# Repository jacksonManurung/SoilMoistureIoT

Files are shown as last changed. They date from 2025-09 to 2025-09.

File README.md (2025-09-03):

# Soil Moisture IoT
Eclosure+SoilMoistureIoT_page-0001
WhatsApp Image 2025-09-03 at 09 00 22_e6ffbfff

## Skematik
SoilMoistureIoT_page-0001

## Koneksi microcontroller dan komponen pasif pendukung
SoilMoistureIoT_page-0002

## Modem dengan beberapa disain komponen pasif pendukung
SoilMoistureIoT_page-0003

## Disain "capacitor decoupling" untuk modem
SoilMoistureIoT_page-0004

## Disain konektor "SIM Card" untuk modem
SoilMoistureIoT_page-0005

## Disain indikator untuk modem
SoilMoistureIoT_page-0006

## Media penyimpanan menggunakan F-RAM
SoilMoistureIoT_page-0007

## Komponen aktif untuk backup system terpisah
SoilMoistureIoT_page-0008

## Antarmuka sensor
SoilMoistureIoT_page-0009

## Disain "multi-purpose" DC regulator dan battery power management system
SoilMoistureIoT_page-0010

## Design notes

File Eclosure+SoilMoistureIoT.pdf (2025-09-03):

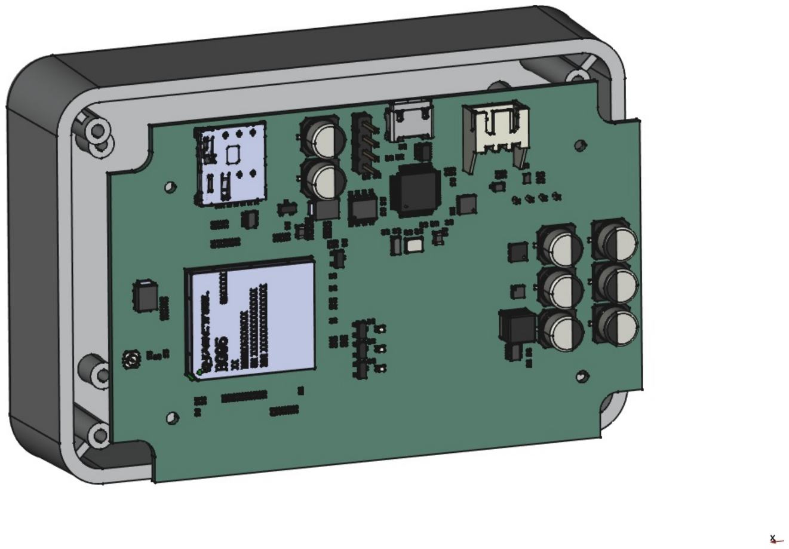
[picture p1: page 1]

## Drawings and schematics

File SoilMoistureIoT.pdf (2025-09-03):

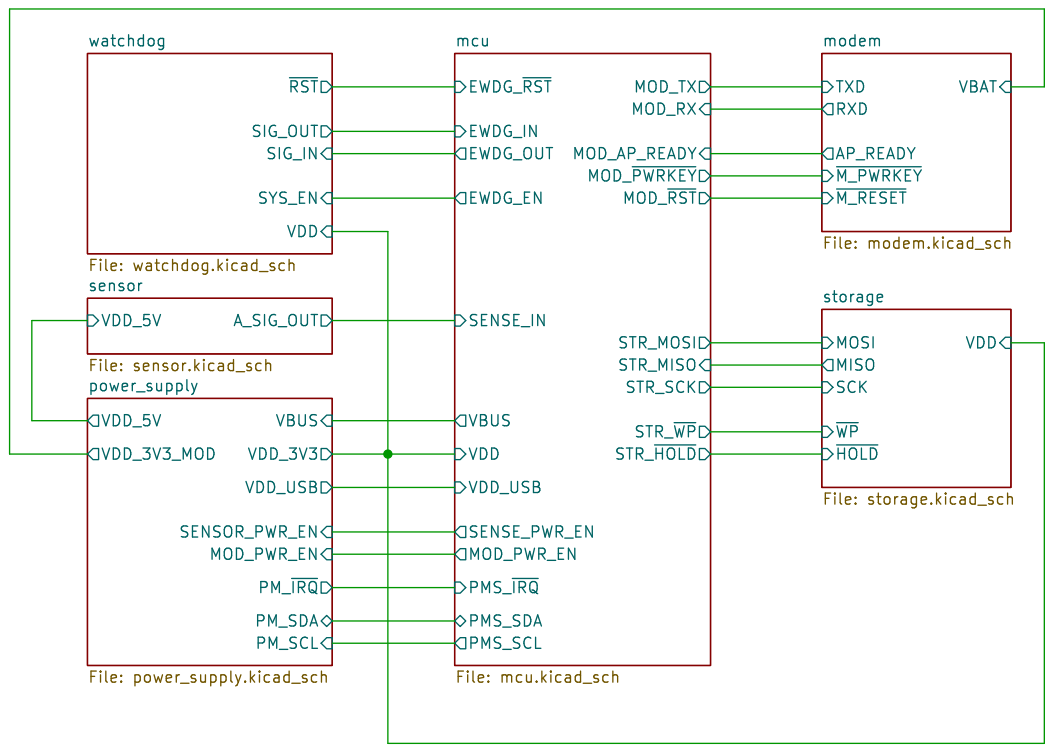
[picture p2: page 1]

Id: 1/10 Title: File: SoilMoistureIoT.kicad_sch Sheet: / STR_~{HOLD} MOD_TX MOD_RX

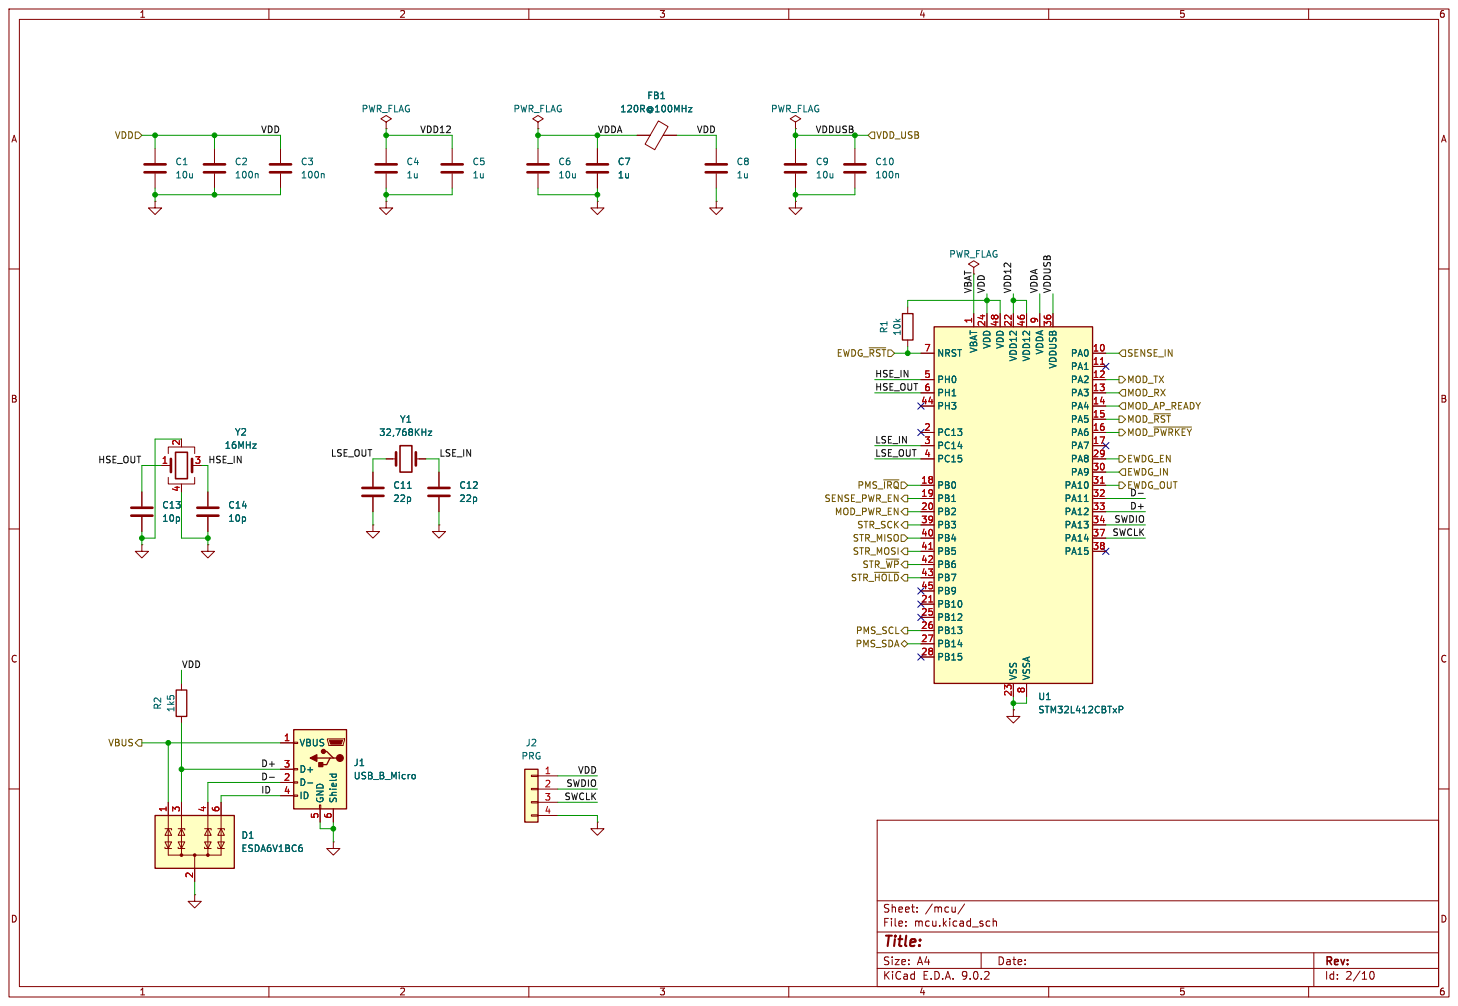
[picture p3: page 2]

Id: 2/10 Title: File: mcu.kicad_sch Sheet: /mcu/ R1 10k

1 VDD 24 VDD 48 VDD12 22 VSS 23 VDD12 46 VSSA

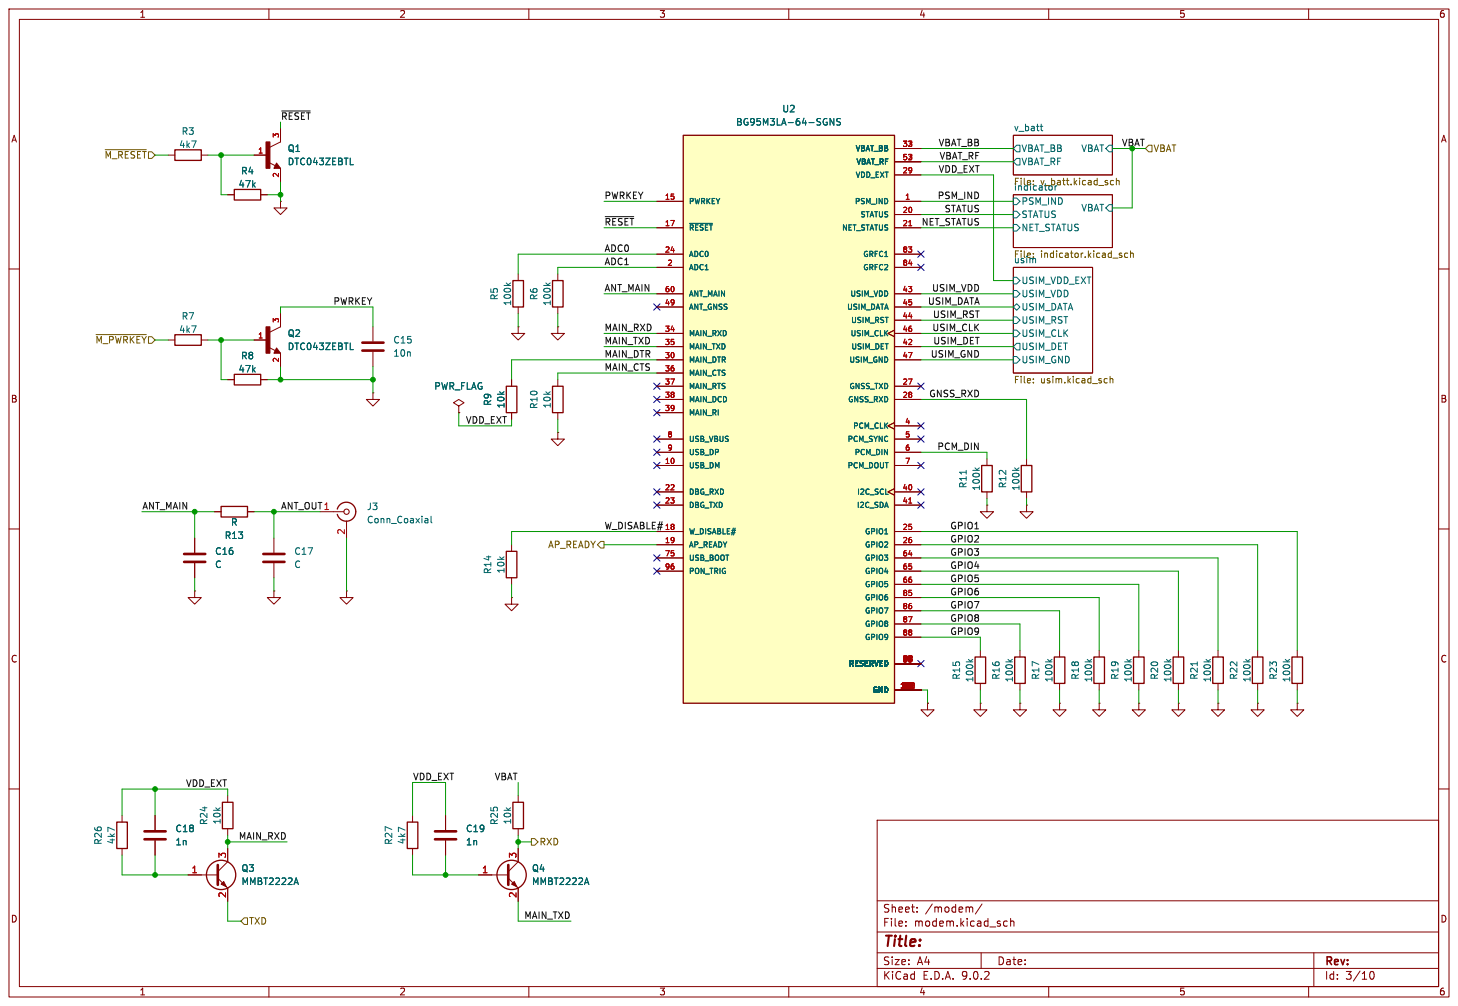
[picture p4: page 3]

Id: 3/10 Title: File: modem.kicad_sch Sheet: /modem/

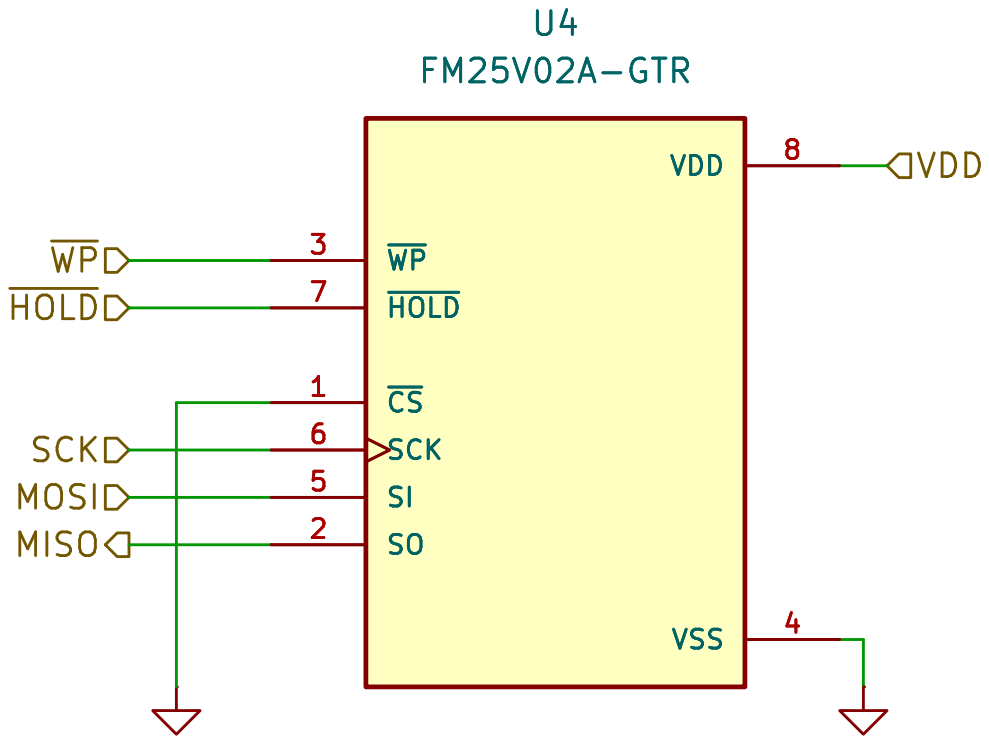
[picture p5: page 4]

Id: 7/10 Title: File: storage.kicad_sch Sheet: /storage/

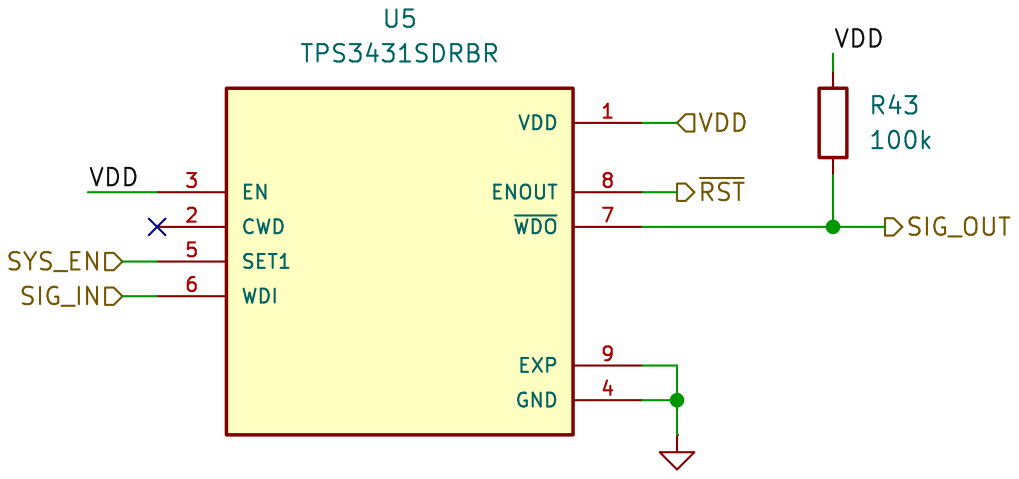
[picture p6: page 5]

Id: 8/10 Title: File: watchdog.kicad_sch Sheet: /watchdog/

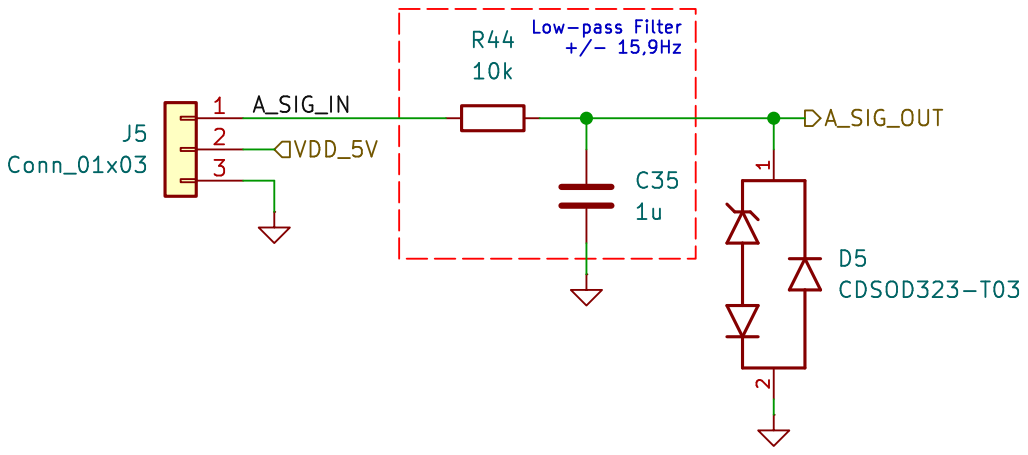
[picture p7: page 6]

Id: 9/10 Title: File: sensor.kicad_sch Sheet: /sensor/

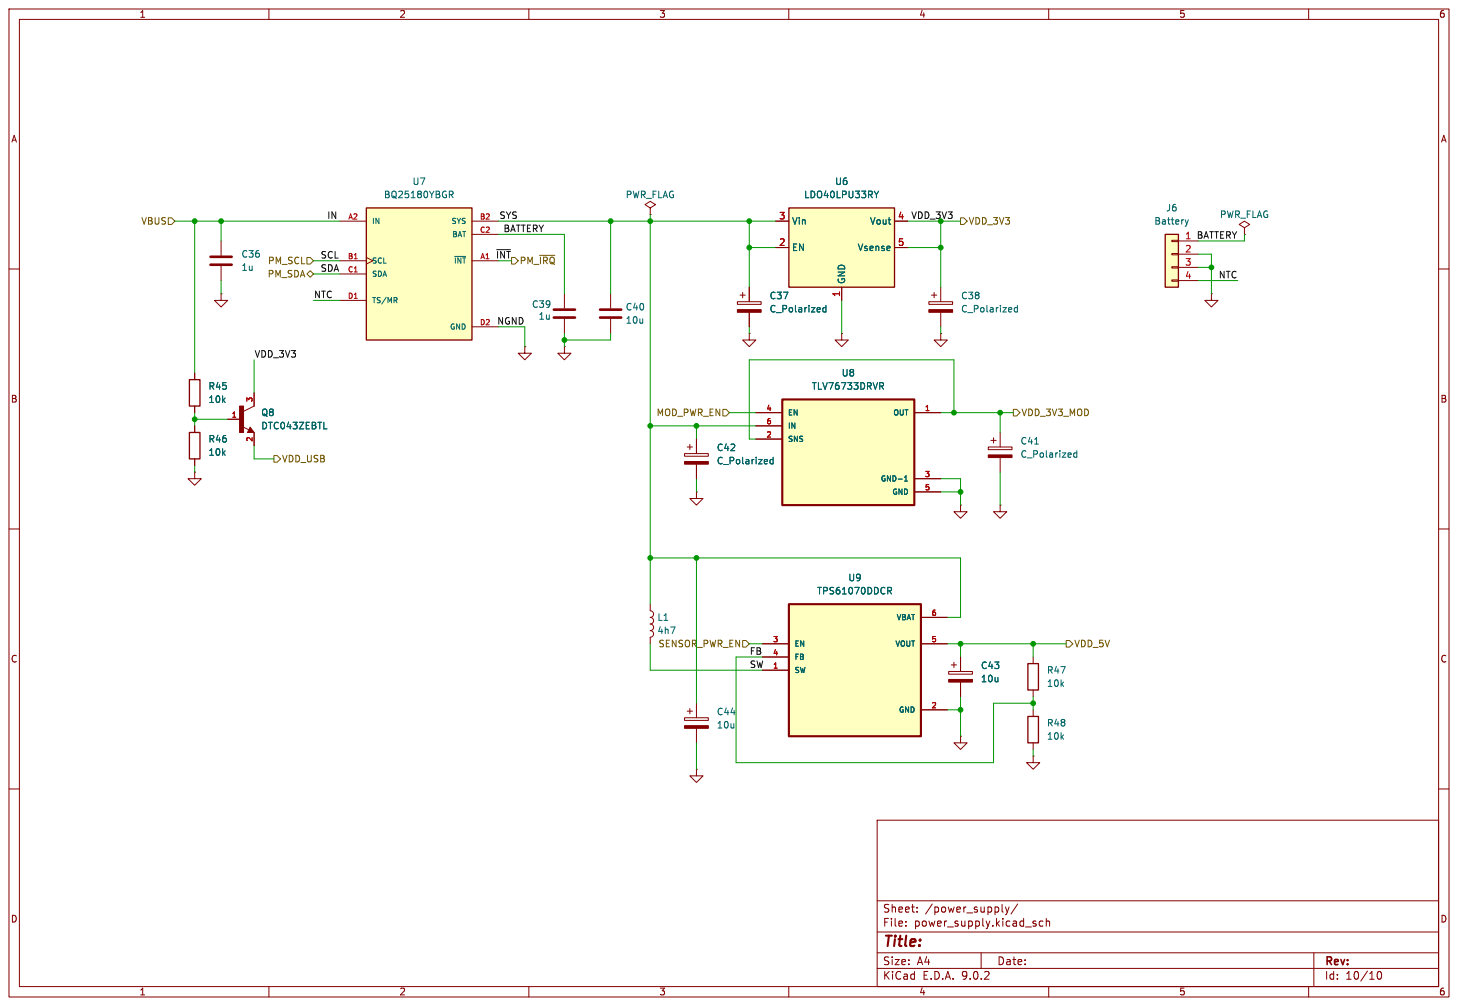
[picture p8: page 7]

Id: 10/10 Title: File: power_supply.kicad_sch Sheet: /power_supply/

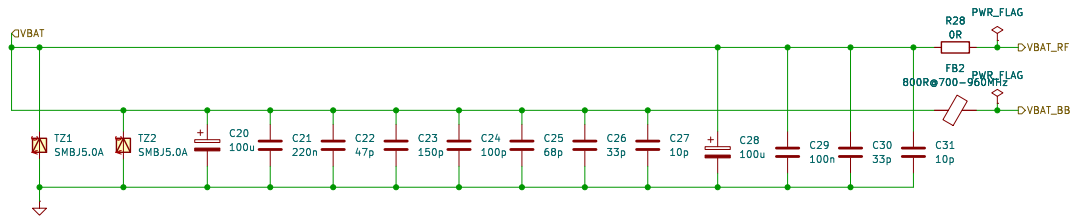
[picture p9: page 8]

Id: 4/10 Title: File: v_batt.kicad_sch Sheet: /modem/v_batt/ C21

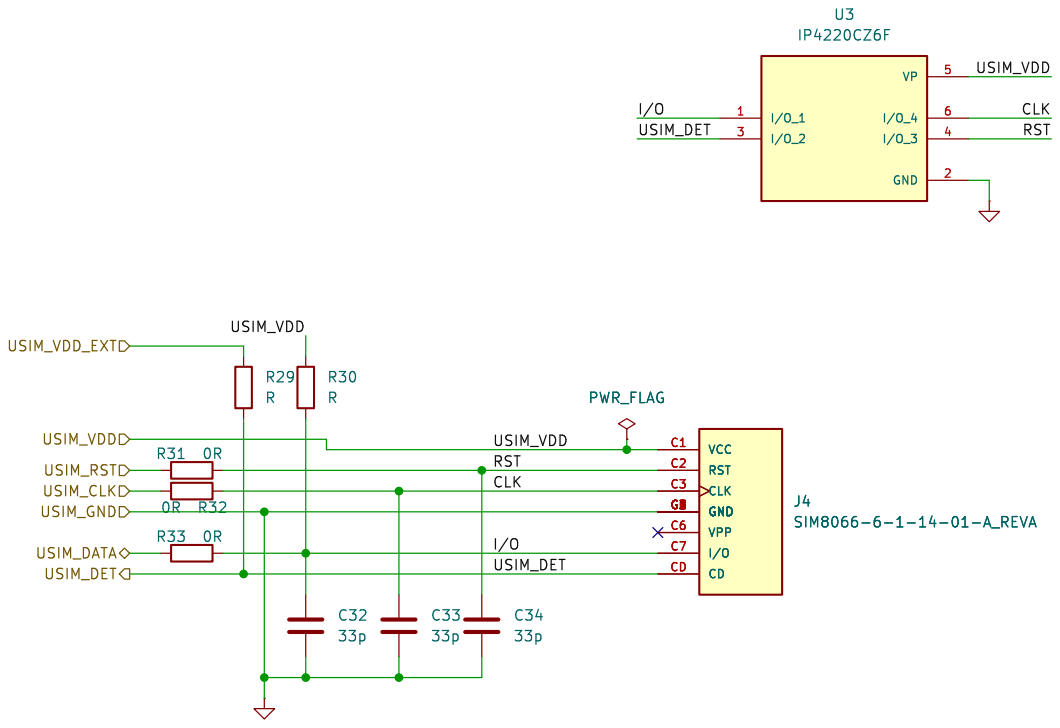
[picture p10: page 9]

Id: 5/10 Title: File: usim.kicad_sch Sheet: /modem/usim/ R31 0R

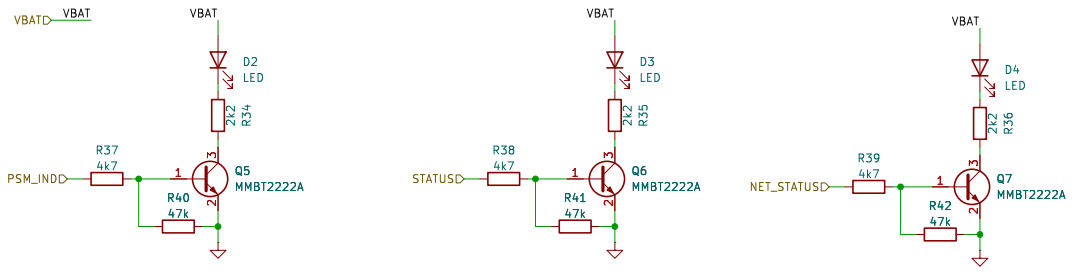
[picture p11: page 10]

Id: 6/10 Title: File: indicator.kicad_sch Sheet: /modem/indicator/

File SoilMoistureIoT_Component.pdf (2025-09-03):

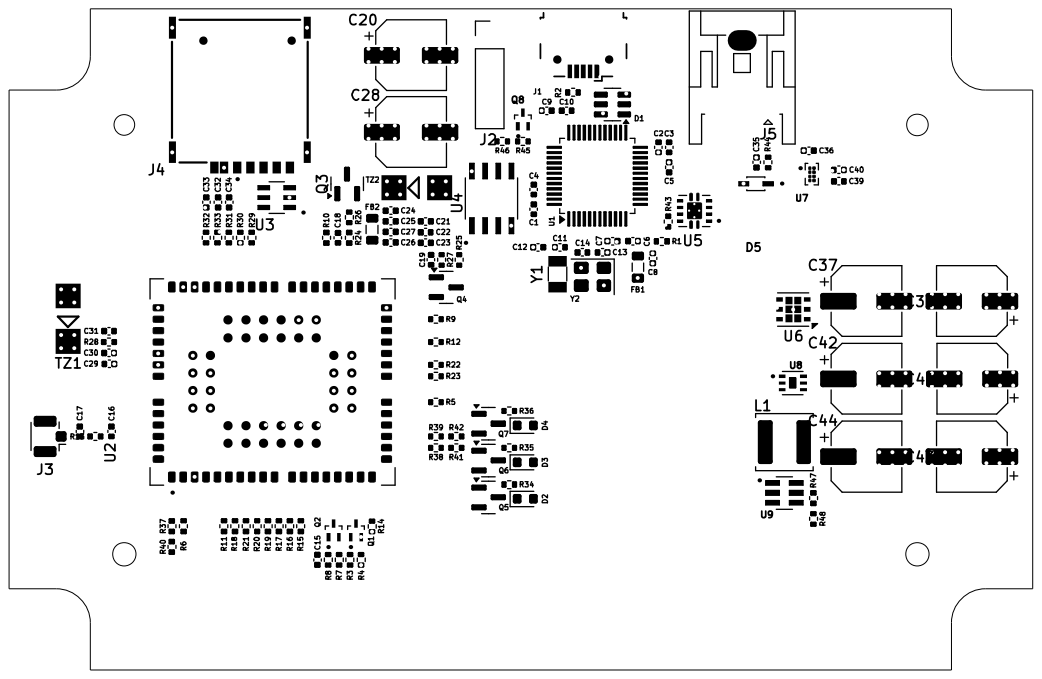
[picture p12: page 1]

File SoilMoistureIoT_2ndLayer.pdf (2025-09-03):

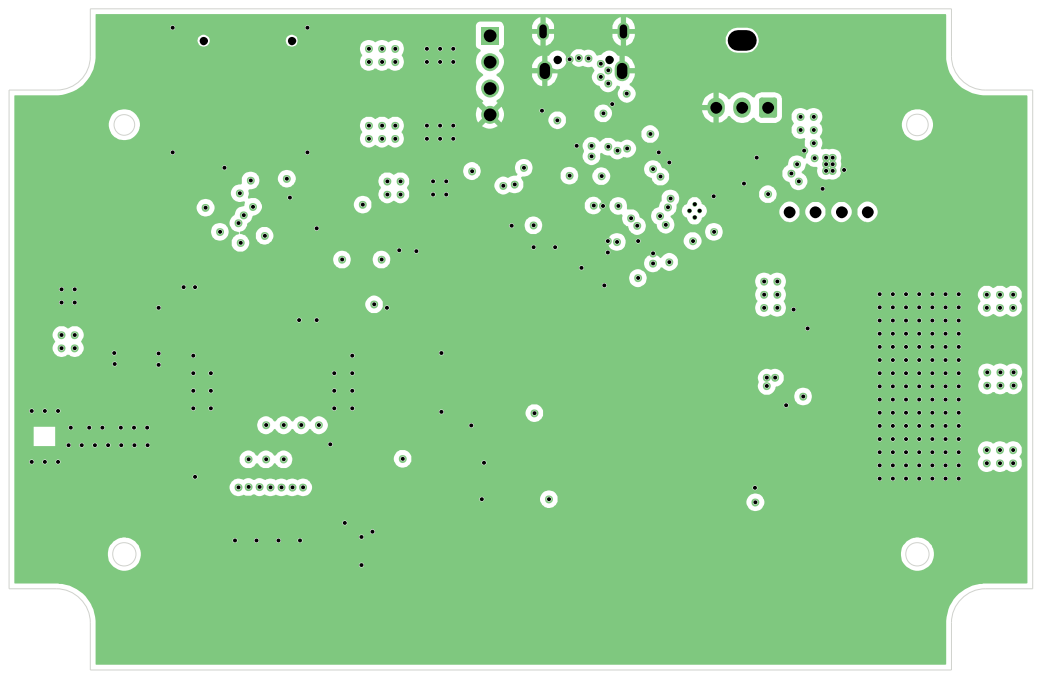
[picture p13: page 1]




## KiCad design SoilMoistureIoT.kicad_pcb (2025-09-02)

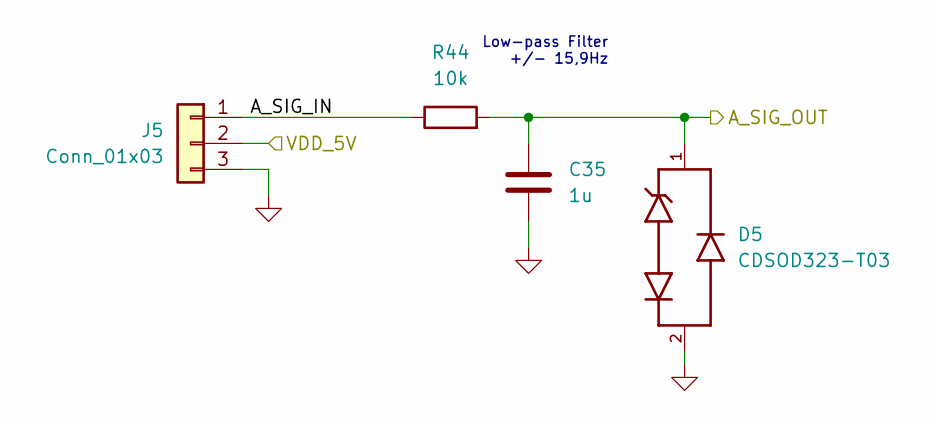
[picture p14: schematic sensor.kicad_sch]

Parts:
C35: 1u; C_0402_1005Metric
D5: CDSOD323-T03; SOD2513X114N; PARTREV 04/23
J5: Conn_01x03; JST_XA_S03B-XASK-1_1x03_P2.50mm_Horizontal
R44: 10k; R_0402_1005Metric

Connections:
/mcu/SENSE_IN: C35.1, D5.1, R44.2; also elsewhere on the board
/power_supply/VDD_5V: J5.2; also elsewhere on the board
/sensor/A_SIG_IN: J5.1, R44.1
GND: C35.2, D5.2, J5.3; also elsewhere on the board

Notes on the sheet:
Low-pass Filter +/- 15,9Hz

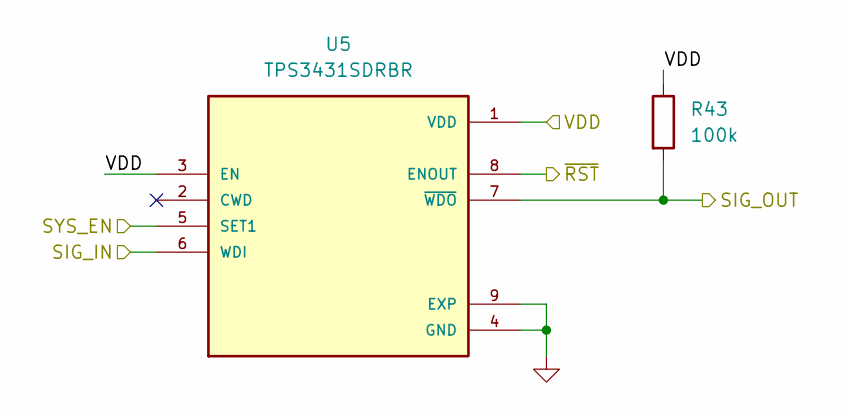
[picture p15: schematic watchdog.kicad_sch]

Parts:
R43: 100k; R_0402_1005Metric
U5: TPS3431SDRBR; IC_TPS3431SDRBR; PARTREV A

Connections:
/mcu/EWDG_EN: U5.5 (SET1); also elsewhere on the board
/mcu/EWDG_IN: R43.2, U5.7 (~WDO); also elsewhere on the board
/mcu/EWDG_OUT: U5.6 (WDI); also elsewhere on the board
/mcu/EWDG_~RST: U5.8 (ENOUT); also elsewhere on the board
/mcu/VDD: R43.1, U5.1 (VDD), U5.3 (EN); also elsewhere on the board
GND: U5.4 (GND), U5.9 (EXP); also elsewhere on the board

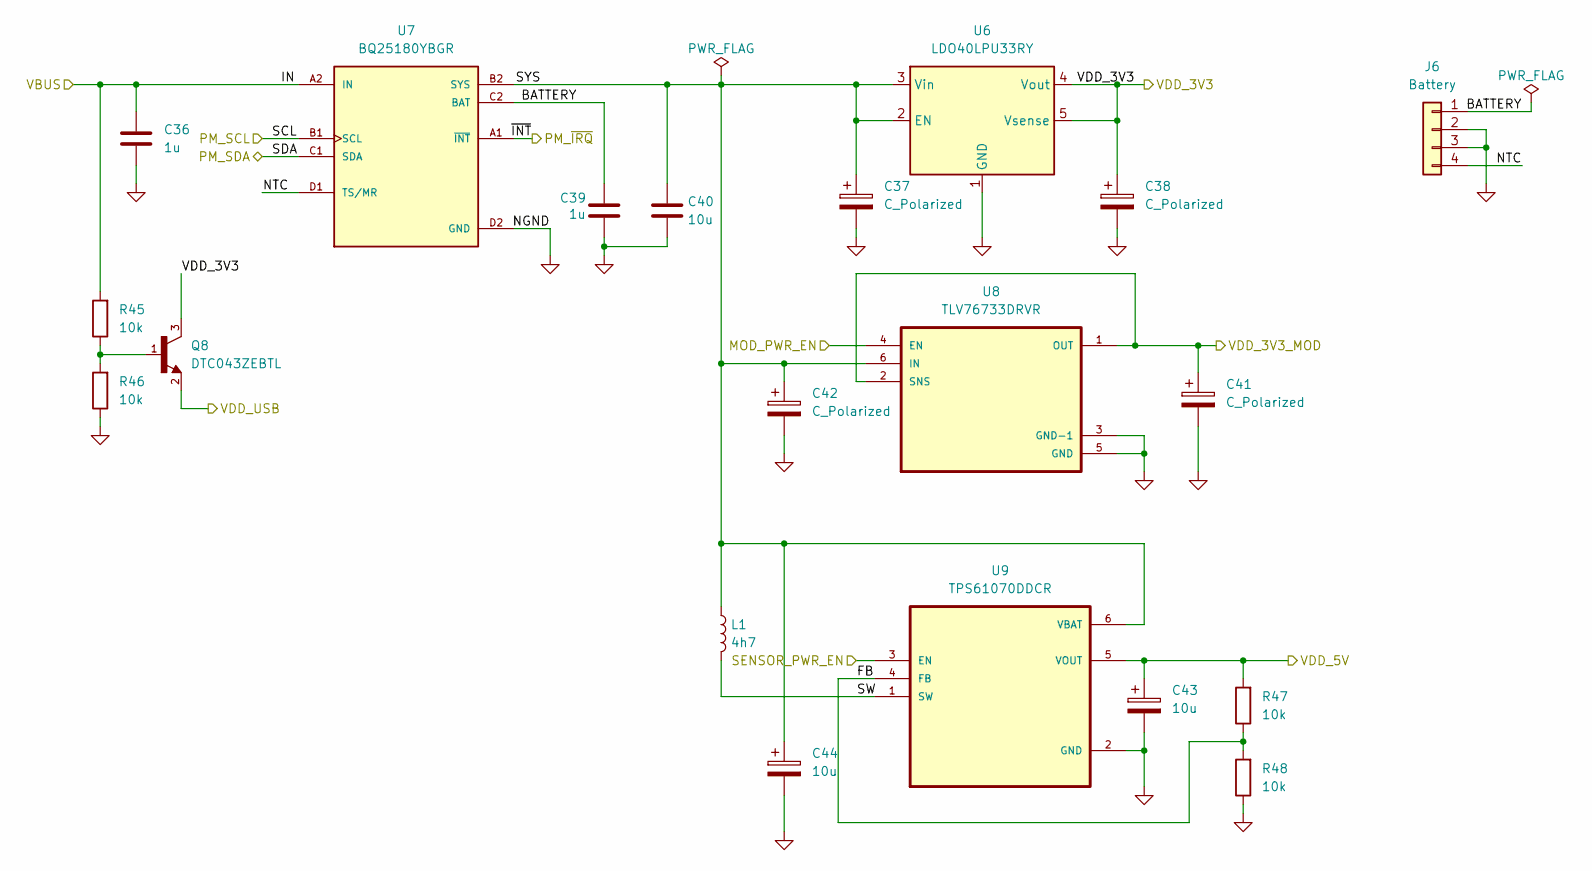
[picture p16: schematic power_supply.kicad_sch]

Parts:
C36, C39: 1u; C_0402_1005Metric
C37, C38, C41, C42: C_Polarized; CP_Elec_6.3x5.7
C40: 10u; C_0402_1005Metric
C43, C44: 10u; CP_Elec_6.3x5.7
J6: Battery; JST_XA_S04B-XASK-1N-BN_1x04_P2.50mm_Horizontal
L1: 4h7; L_APV_ANR5045
Q8: DTC043ZEBTL; SOTFL50P160X85-3N; PARTREV 002
R45, R46, R47, R48: 10k; R_0402_1005Metric
U6: LDO40LPU33RY; DFN-6-1EP_3x3mm_P0.95mm_EP1.7x2.6mm
U7: BQ25180YBGR; IC_BQ25180YBGR; PARTREV C
U8: TLV76733DRVR; SON65P200X200X80-7N
U9: TPS61070DDCR; SOT95P280X110-6N

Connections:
/mcu/MOD_PWR_EN: U8.4 (EN); also elsewhere on the board
/mcu/SENSE_PWR_EN: U9.3 (EN); also elsewhere on the board
/mcu/VDD: C38.1, Q8.3, U6.4 (Vout), U6.5 (Vsense); also elsewhere on the board
/mcu/VDDUSB: Q8.2; also elsewhere on the board
/modem/VBAT: C41.1, U8.1 (OUT), U8.2 (SNS); also elsewhere on the board
/power_supply/BATTERY: C39.1, J6.1, U7.C2 (BAT)
/power_supply/FB: R47.1, R48.2, U9.4 (FB)
/power_supply/IN: C36.1, R45.2, U7.A2 (IN); also elsewhere on the board
/power_supply/NTC: J6.4, U7.D1 (TS/MR)
/power_supply/SCL: U7.B1 (SCL); also elsewhere on the board
/power_supply/SDA: U7.C1 (SDA); also elsewhere on the board
/power_supply/SW: L1.2, U9.1 (SW)
/power_supply/SYS: C37.1, C40.1, C42.1, C44.1, L1.1, U6.2 (EN), U6.3 (Vin), U7.B2 (SYS), U8.6 (IN), U9.6 (VBAT)
/power_supply/VDD_5V: C43.1, R47.2, U9.5 (VOUT); also elsewhere on the board
/power_supply/~INT: U7.A1 (~INT); also elsewhere on the board
GND: C36.2, C37.2, C38.2, C39.2, C40.2, C41.2, C42.2, C43.2, C44.2, J6.2, J6.3, R46.1, R48.1, U6.1 (GND), U6.7 (GND), U7.D2 (GND), U8.3 (GND-1), U8.5 (GND), U9.2 (GND); also elsewhere on the board
unnamed: Q8.1, R45.1, R46.2

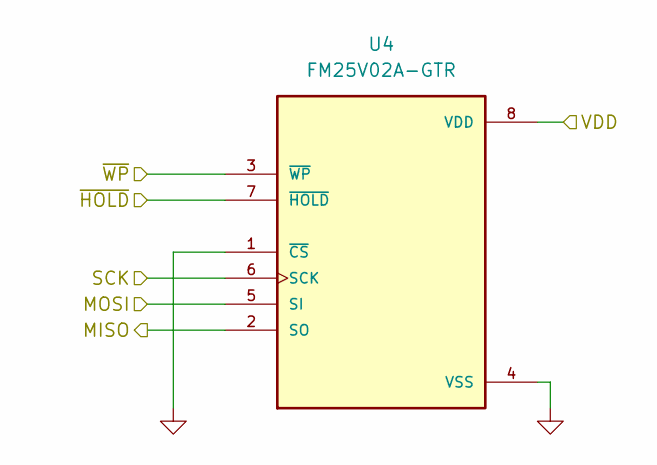
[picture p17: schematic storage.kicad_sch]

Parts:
U4: FM25V02A-GTR; SOIC127P602X172-8N

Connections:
/mcu/STR_MISO: U4.2 (SO); also elsewhere on the board
/mcu/STR_MOSI: U4.5 (SI); also elsewhere on the board
/mcu/STR_SCK: U4.6 (SCK); also elsewhere on the board
/mcu/STR_~HOLD: U4.7 (~HOLD); also elsewhere on the board
/mcu/STR_~WP: U4.3 (~WP); also elsewhere on the board
/mcu/VDD: U4.8 (VDD); also elsewhere on the board
GND: U4.1 (~CS), U4.4 (VSS); also elsewhere on the board

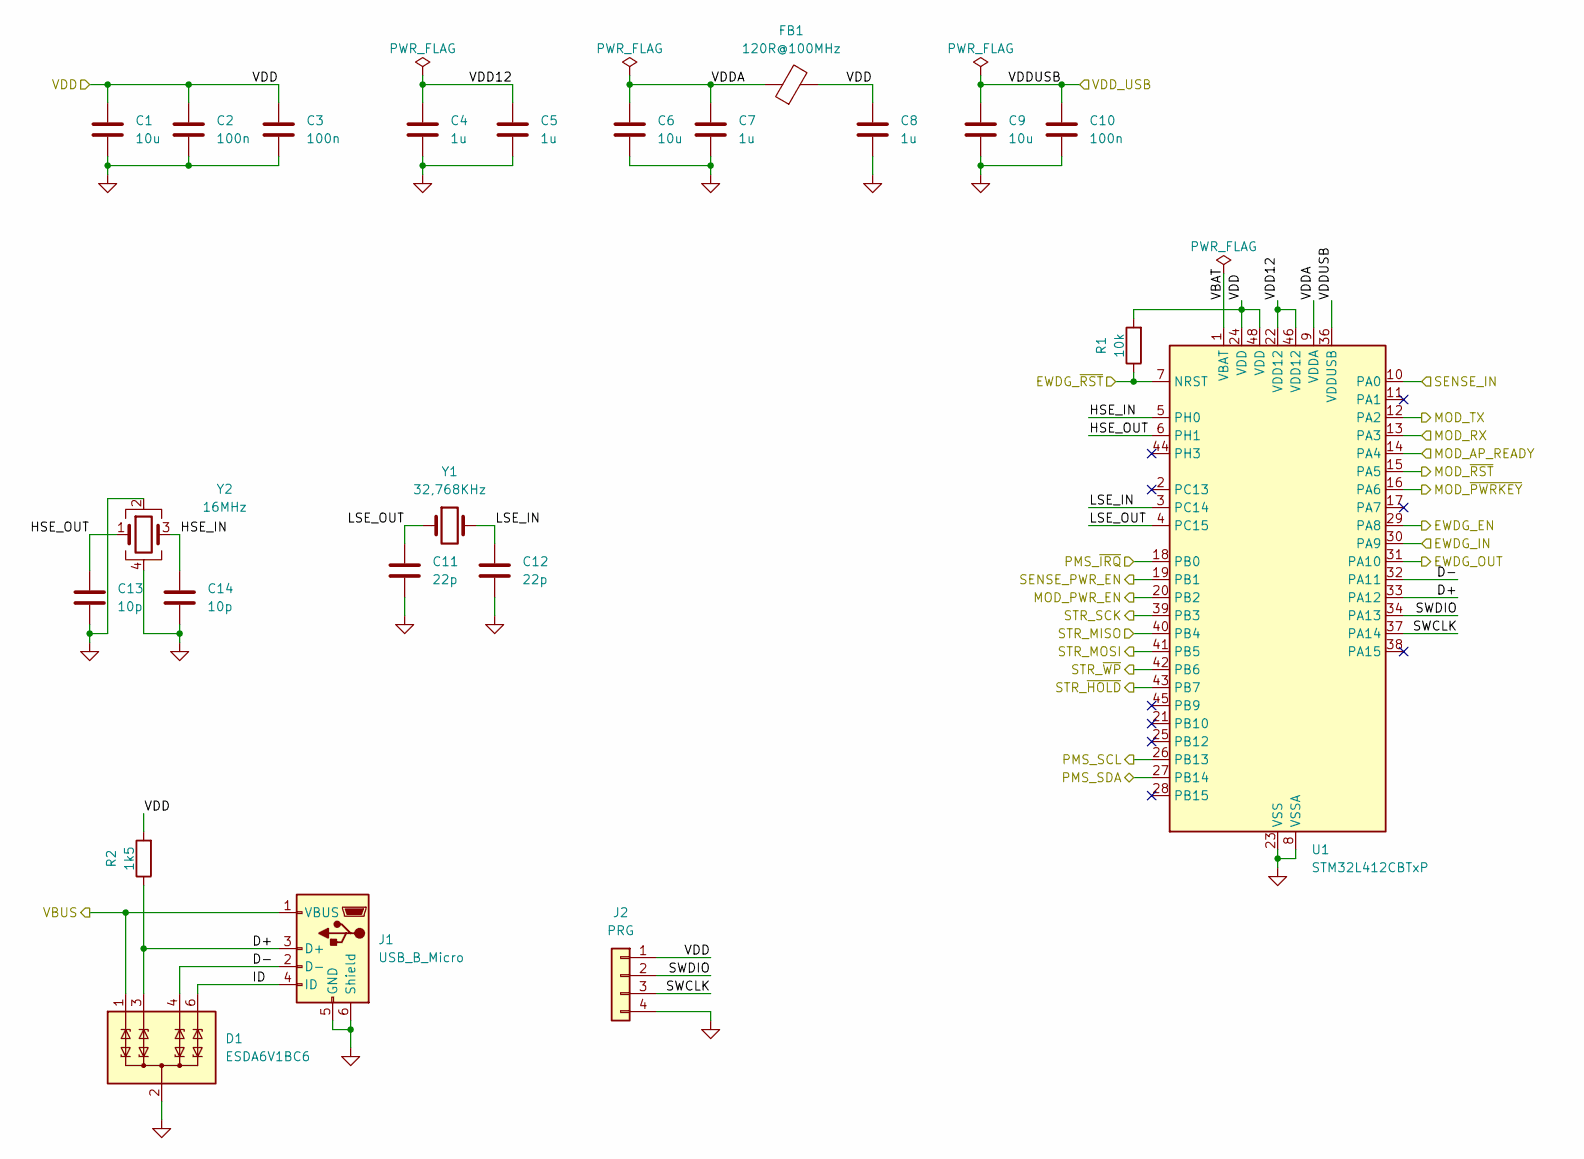
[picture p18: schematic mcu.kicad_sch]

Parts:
C1, C6, C9: 10u; C_0402_1005Metric
C2, C3, C10: 100n; C_0402_1005Metric
C4, C5, C7, C8: 1u; C_0402_1005Metric
C11, C12: 22p; C_0402_1005Metric
C13, C14: 10p; C_0402_1005Metric
D1: ESDA6V1BC6; SOT-23-6
FB1: 120R@100MHz; L_0805_2012Metric
J1: USB_B_Micro; USB_Micro-B_Wuerth_629105150521
J2: PRG; PinHeader_1x04_P2.54mm_Vertical
R1: 10k; R_0402_1005Metric
R2: 1k5; R_0402_1005Metric
U1: STM32L412CBTxP; LQFP-48_7x7mm_P0.5mm
Y1: 32,768KHz; Crystal_SMD_3215-2Pin_3.2x1.5mm
Y2: 16MHz; Crystal_SMD_3225-4Pin_3.2x2.5mm

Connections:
/mcu/D+: D1.3 (TVS2), J1.3 (D+), R2.1, U1.33 (PA12)
/mcu/D-: D1.4 (TVS3), J1.2 (D-), U1.32 (PA11)
/mcu/EWDG_EN: U1.29 (PA8); also elsewhere on the board
/mcu/EWDG_IN: U1.30 (PA9); also elsewhere on the board
/mcu/EWDG_OUT: U1.31 (PA10); also elsewhere on the board
/mcu/EWDG_~RST: R1.1, U1.7 (NRST); also elsewhere on the board
/mcu/HSE_IN: C14.1, U1.5 (PH0), Y2.3
/mcu/HSE_OUT: C13.1, U1.6 (PH1), Y2.1
/mcu/ID: D1.6 (TVS4), J1.4 (ID)
/mcu/LSE_IN: C12.1, U1.3 (PC14), Y1.2
/mcu/LSE_OUT: C11.1, U1.4 (PC15), Y1.1
/mcu/MOD_AP_READY: U1.14 (PA4); also elsewhere on the board
/mcu/MOD_PWR_EN: U1.20 (PB2); also elsewhere on the board
/mcu/MOD_RX: U1.13 (PA3); also elsewhere on the board
/mcu/MOD_TX: U1.12 (PA2); also elsewhere on the board
/mcu/MOD_~PWRKEY: U1.16 (PA6); also elsewhere on the board
/mcu/MOD_~RST: U1.15 (PA5); also elsewhere on the board
/mcu/SENSE_IN: U1.10 (PA0); also elsewhere on the board
/mcu/SENSE_PWR_EN: U1.19 (PB1); also elsewhere on the board
/mcu/STR_MISO: U1.40 (PB4); also elsewhere on the board
/mcu/STR_MOSI: U1.41 (PB5); also elsewhere on the board
/mcu/STR_SCK: U1.39 (PB3); also elsewhere on the board
/mcu/STR_~HOLD: U1.43 (PB7); also elsewhere on the board
/mcu/STR_~WP: U1.42 (PB6); also elsewhere on the board
/mcu/SWCLK: J2.3, U1.37 (PA14)
/mcu/SWDIO: J2.2, U1.34 (PA13)
/mcu/VBAT: U1.1 (VBAT)
/mcu/VDD: C1.1, C2.1, C3.1, C8.1, FB1.2, J2.1, R1.2, R2.2, U1.24 (VDD), U1.48 (VDD); also elsewhere on the board
/mcu/VDD12: C4.1, C5.1, U1.22 (VDD12), U1.46 (VDD12)
/mcu/VDDA: C6.1, C7.1, FB1.1, U1.9 (VDDA)
/mcu/VDDUSB: C9.1, C10.1, U1.36 (VDDUSB); also elsewhere on the board
/power_supply/IN: D1.1 (TVS1), J1.1 (VBUS); also elsewhere on the board
/power_supply/SCL: U1.26 (PB13); also elsewhere on the board
/power_supply/SDA: U1.27 (PB14); also elsewhere on the board
/power_supply/~INT: U1.18 (PB0); also elsewhere on the board
GND: C1.2, C2.2, C3.2, C4.2, C5.2, C6.2, C7.2, C8.2, C9.2, C10.2, C11.2, C12.2, C13.2, C14.2, D1.2 (COM), D1.5 (COM), J1.5 (GND), J1.6 (Shield), J2.4, U1.8 (VSSA), U1.23 (VSS), U1.35 (VSS), U1.47 (VSS), Y2.2, Y2.4; also elsewhere on the board

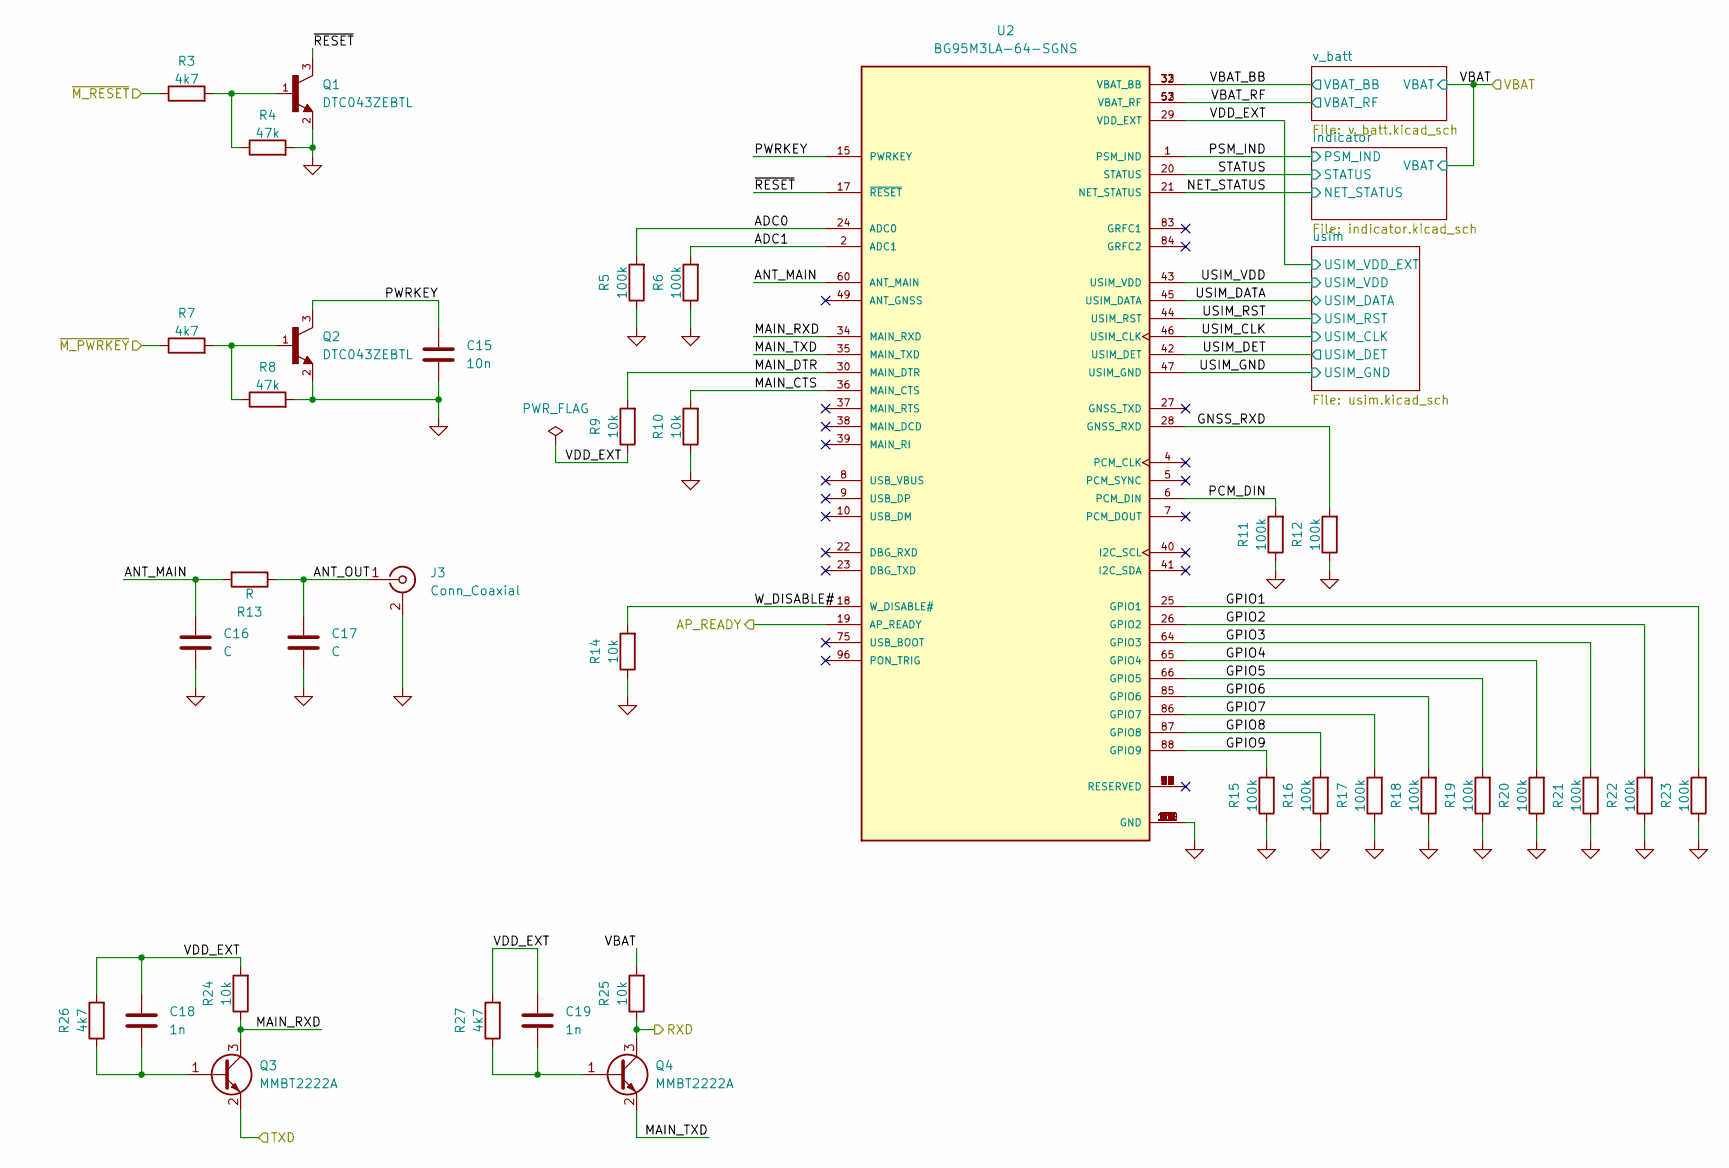
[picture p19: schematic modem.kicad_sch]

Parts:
C15: 10n; C_0402_1005Metric
C16, C17: C; C_0402_1005Metric
C18, C19: 1n; C_0402_1005Metric
J3: Conn_Coaxial; U.FL_Hirose_U.FL-R-SMT-1_Vertical
Q1, Q2: DTC043ZEBTL; SOTFL50P160X85-3N; PARTREV 002
Q3, Q4: MMBT2222A; SOT-23
R3, R7, R26, R27: 4k7; R_0402_1005Metric
R4, R8: 47k; R_0402_1005Metric
R5, R6, R11, R12, R15, R16, R17, R18, R19, R20, R21, R22, R23: 100k; R_0402_1005Metric
R9, R10, R14, R24, R25: 10k; R_0402_1005Metric
R13: R; R_0402_1005Metric
U2: BG95M3LA-64-SGNS; XCVR_BG95M3LA-64-SGNS

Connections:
/mcu/MOD_AP_READY: U2.19 (AP_READY); also elsewhere on the board
/mcu/MOD_RX: Q4.3 (C), R25.1; also elsewhere on the board
/mcu/MOD_TX: Q3.2 (E); also elsewhere on the board
/mcu/MOD_~PWRKEY: R7.1; also elsewhere on the board
/mcu/MOD_~RST: R3.1; also elsewhere on the board
/modem/ADC0: R5.2, U2.24 (ADC0)
/modem/ADC1: R6.2, U2.2 (ADC1)
/modem/ANT_MAIN: C16.1, R13.2, U2.60 (ANT_MAIN)
/modem/ANT_OUT: C17.1, J3.1 (In), R13.1
/modem/GNSS_RXD: R12.2, U2.28 (GNSS_RXD)
/modem/GPIO1: R23.2, U2.25 (GPIO1)
/modem/GPIO2: R22.2, U2.26 (GPIO2)
/modem/GPIO3: R21.2, U2.64 (GPIO3)
/modem/GPIO4: R20.2, U2.65 (GPIO4)
/modem/GPIO5: R19.2, U2.66 (GPIO5)
/modem/GPIO6: R18.2, U2.85 (GPIO6)
/modem/GPIO7: R17.2, U2.86 (GPIO7)
/modem/GPIO8: R16.2, U2.87 (GPIO8)
/modem/GPIO9: R15.2, U2.88 (GPIO9)
/modem/MAIN_CTS: R10.2, U2.36 (MAIN_CTS)
/modem/MAIN_DTR: R9.2, U2.30 (MAIN_DTR)
/modem/MAIN_RXD: Q3.3 (C), R24.1, U2.34 (MAIN_RXD)
/modem/MAIN_TXD: Q4.2 (E), U2.35 (MAIN_TXD)
/modem/NET_STATUS: U2.21 (NET_STATUS); also elsewhere on the board
/modem/PCM_DIN: R11.2, U2.6 (PCM_DIN)
/modem/PSM_IND: U2.1 (PSM_IND); also elsewhere on the board
/modem/PWRKEY: C15.1, Q2.3, U2.15 (PWRKEY)
/modem/STATUS: U2.20 (STATUS); also elsewhere on the board
/modem/USIM_CLK: U2.46 (USIM_CLK); also elsewhere on the board
/modem/USIM_DATA: U2.45 (USIM_DATA); also elsewhere on the board
/modem/USIM_DET: U2.42 (USIM_DET); also elsewhere on the board
/modem/USIM_RST: U2.44 (USIM_RST); also elsewhere on the board
/modem/USIM_VDD: U2.43 (USIM_VDD); also elsewhere on the board
/modem/VBAT: R25.2; also elsewhere on the board
/modem/VBAT_BB: U2.32 (VBAT_BB), U2.33 (VBAT_BB); also elsewhere on the board
/modem/VBAT_RF: U2.52 (VBAT_RF), U2.53 (VBAT_RF); also elsewhere on the board
/modem/VDD_EXT: C18.1, C19.1, R9.1, R24.2, R26.2, R27.2, U2.29 (VDD_EXT); also elsewhere on the board
/modem/W_DISABLE#: R14.2, U2.18 (W_DISABLE#)
/modem/~RESET: Q1.3, U2.17 (~RESET)
GND: C15.2, C16.2, C17.2, J3.2 (Ext), Q1.2, Q2.2, R4.2, R5.1, R6.1, R8.2, R10.1, R11.1, R12.1, R14.1, R15.1, R16.1, R17.1, R18.1, R19.1, R20.1, R21.1, R22.1, R23.1, U2.3 (GND), U2.31 (GND), U2.47 (USIM_GND), U2.48 (GND), U2.50 (GND), U2.54 (GND), U2.55 (GND), U2.58 (GND), U2.59 (GND), U2.61 (GND), U2.62 (GND), U2.67 (GND), U2.68 (GND), U2.69 (GND), U2.70 (GND), U2.71 (GND), U2.72 (GND), U2.73 (GND), U2.74 (GND), U2.79 (GND), U2.80 (GND), U2.81 (GND), U2.82 (GND), U2.89 (GND), U2.90 (GND), U2.91 (GND), U2.100 (GND), U2.101 (GND), U2.102 (GND); also elsewhere on the board
unnamed: Q1.1, R3.2, R4.1
unnamed: Q2.1, R7.2, R8.1
unnamed: C18.2, Q3.1 (B), R26.1
unnamed: C19.2, Q4.1 (B), R27.1

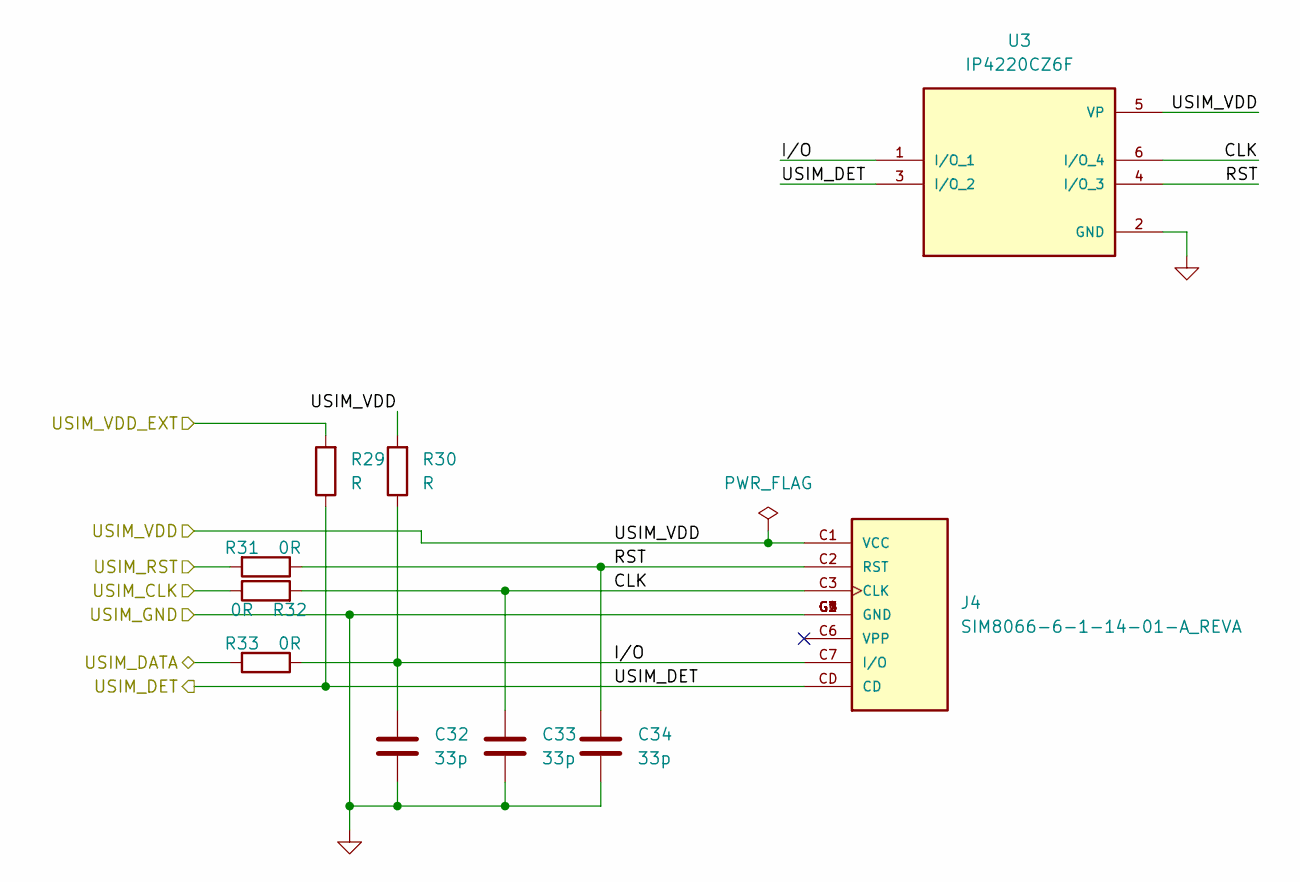
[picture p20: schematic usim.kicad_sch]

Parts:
C32, C33, C34: 33p; C_0402_1005Metric
J4: SIM8066-6-1-14-01-A_REVA; GCT_SIM8066-6-1-14-01-A_REVA; PARTREV REVA
R29, R30: R; R_0402_1005Metric
R31, R32, R33: 0R; R_0402_1005Metric
U3: IP4220CZ6F; SOT95P275X110-6N; PARTREV 5

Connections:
/modem/USIM_CLK: R32.1; also elsewhere on the board
/modem/USIM_DATA: R33.2; also elsewhere on the board
/modem/USIM_DET: J4.CD, R29.1, U3.3 (I/O_2); also elsewhere on the board
/modem/USIM_RST: R31.2; also elsewhere on the board
/modem/USIM_VDD: J4.C1 (VCC), R30.2, U3.5 (VP); also elsewhere on the board
/modem/VDD_EXT: R29.2; also elsewhere on the board
/modem/usim/CLK: C33.1, J4.C3 (CLK), R32.2, U3.6 (I/O_4)
/modem/usim/RST: C34.1, J4.C2 (RST), R31.1, U3.4 (I/O_3)
GND: C32.2, C33.2, C34.2, J4.C5 (GND), J4.G1 (GND), J4.G2 (GND), J4.G3 (GND), J4.G4 (GND), U3.2 (GND); also elsewhere on the board

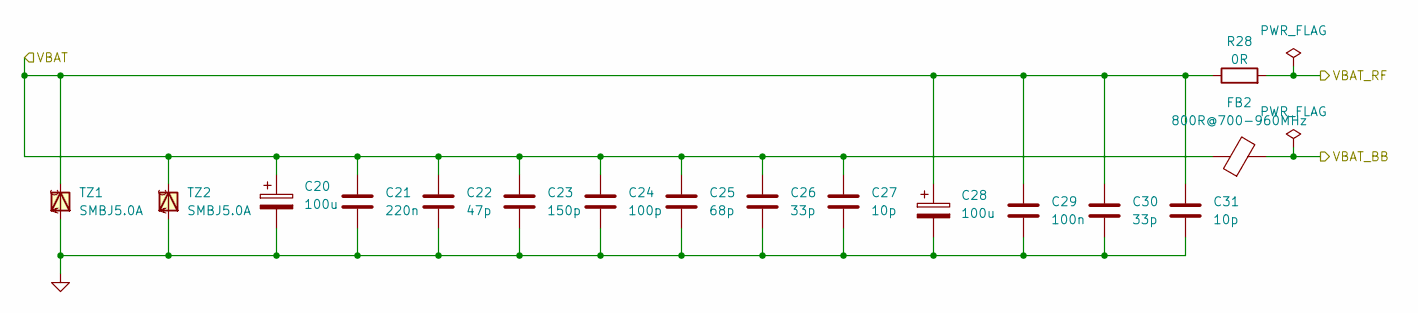
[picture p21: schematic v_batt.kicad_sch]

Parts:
C20, C28: 100u; CP_Elec_6.3x5.4
C21: 220n; C_0402_1005Metric
C22: 47p; C_0402_1005Metric
C23: 150p; C_0402_1005Metric
C24: 100p; C_0402_1005Metric
C25: 68p; C_0402_1005Metric
C26, C30: 33p; C_0402_1005Metric
C27, C31: 10p; C_0402_1005Metric
C29: 100n; C_0402_1005Metric
FB2: 800R@700-960MHz; L_0805_2012Metric
R28: 0R; R_0402_1005Metric
TZ1, TZ2: SMBJ5.0A; SMB

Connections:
/modem/VBAT: C20.1, C21.1, C22.1, C23.1, C24.1, C25.1, C26.1, C27.1, C28.1, C29.1, C30.1, C31.1, FB2.1, R28.1, TZ1.C, TZ2.C; also elsewhere on the board
/modem/VBAT_BB: FB2.2; also elsewhere on the board
/modem/VBAT_RF: R28.2; also elsewhere on the board
GND: C20.2, C21.2, C22.2, C23.2, C24.2, C25.2, C26.2, C27.2, C28.2, C29.2, C30.2, C31.2, TZ1.A, TZ2.A; also elsewhere on the board

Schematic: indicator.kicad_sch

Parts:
D2, D3, D4: LED; LED_0603_1608Metric
Q5, Q6, Q7: MMBT2222A; SOT-23
R34, R35, R36: 2k2; R_0402_1005Metric
R37, R38, R39: 4k7; R_0402_1005Metric
R40, R41, R42: 47k; R_0402_1005Metric

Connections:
/modem/NET_STATUS: R39.2; also elsewhere on the board
/modem/PSM_IND: R37.2; also elsewhere on the board
/modem/STATUS: R38.2; also elsewhere on the board
/modem/VBAT: D2.2 (A), D3.2 (A), D4.2 (A); also elsewhere on the board
GND: Q5.2 (E), Q6.2 (E), Q7.2 (E), R40.1, R41.1, R42.1; also elsewhere on the board
unnamed: D2.1 (K), R34.2
unnamed: D3.1 (K), R35.2
unnamed: D4.1 (K), R36.2
unnamed: Q5.1 (B), R37.1, R40.2
unnamed: Q5.3 (C), R34.1
unnamed: Q6.1 (B), R38.1, R41.2
unnamed: Q6.3 (C), R35.1
unnamed: Q7.1 (B), R39.1, R42.2
unnamed: Q7.3 (C), R36.1

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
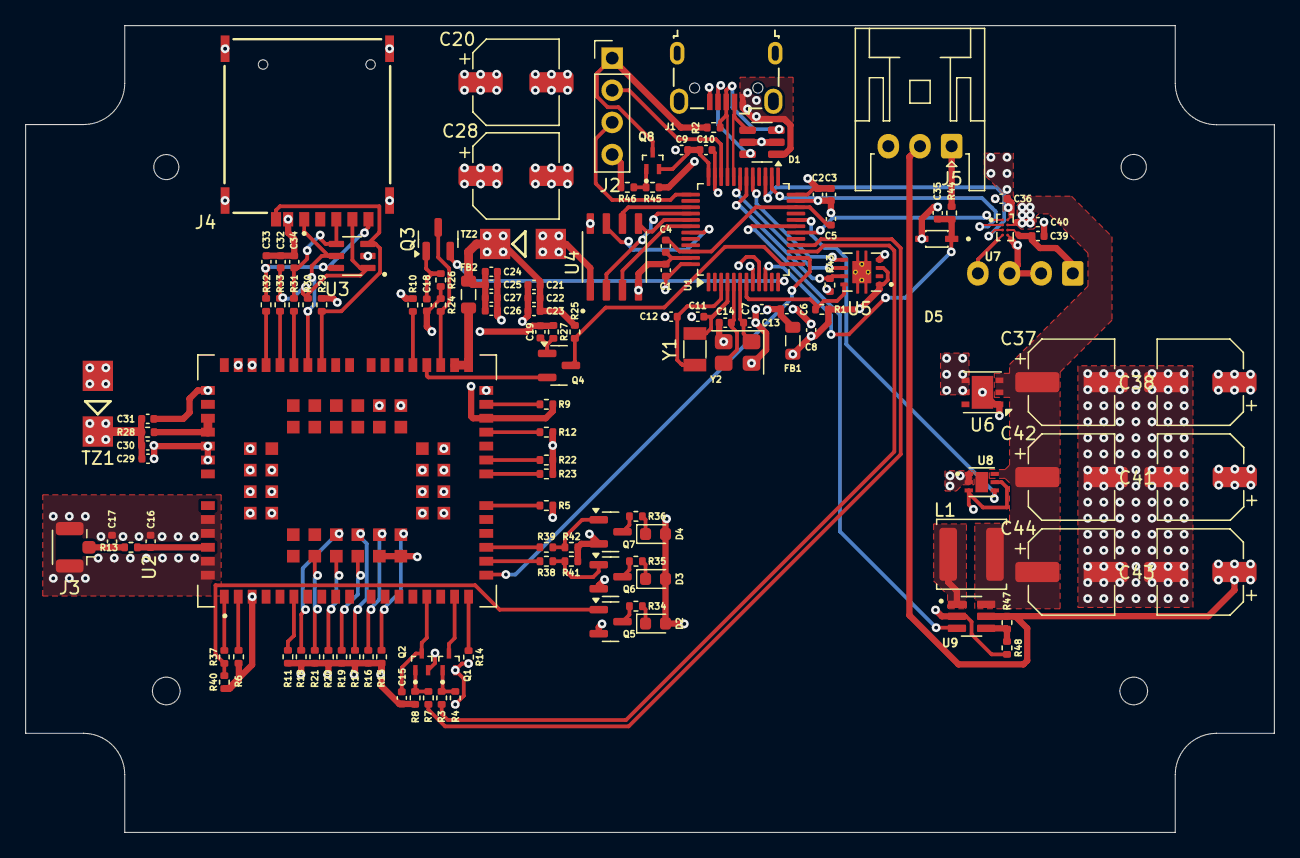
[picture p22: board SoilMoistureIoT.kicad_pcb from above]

Board: 4 copper layers, 98.7 x 63.8 mm, 127 parts (1 on the bottom side), 93 nets.

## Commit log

2025-08-29 initial project
    [SoilMoistureIoT.kicad_pcb, SoilMoistureIoT.kicad_sch]
2025-09-01 adding some component
    [SoilMoistureIoT.kicad_sch, indicator.kicad_sch, mcu.kicad_sch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]
2025-09-02 Layout was finish
    [SoilMoistureIoT.kicad_pcb, mcu.kicad_sch, modem.kicad_sch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]
